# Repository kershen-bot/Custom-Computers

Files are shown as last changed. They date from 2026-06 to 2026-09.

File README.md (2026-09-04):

 # Custom-Computer

 This is a fully custom laptop that is built around a LattePanda Mu, which is a computer module that is credit card-sized. This project took around two to three and a half months. This project is inspired by Ben Makes Everything and Bryan. The specific video by Ben Makes Everything that I used is "https://www.youtube.com/watch?v=o00P7wHbd2c," and the video by Bryan that I used is "https://www.youtube.com/watch?v=fks3PBodyiE." Bryan's website is "https://www.byran.ee/" 

 Below is an image of the full shell of the custom laptop without the hinge mechanism and the internal components.

------------------------------------------------------------------------------------------------------------------------------------------


Configuration of the Lattepanda Mu,
------------------------------------------------------------------------------------------------------------------------------------------
  The exact size of the Lattepanda Mu is 69.6MM by 60MM, and the standard credit card is 85.6MM by 54MM it is very. The Lattepanda Mu has an  Intel X86 chip. It can be configured with an   N100  or an  N305 chip.  The ram that on the Lattepanda Mu is 16GB of LPDDR5 4800MT/s, and for storage, it can be equipped with an M.2 2230 NVME SSD or slash and a 64GB eMMC 5.1 Storage. And of course it has a wifi card, so you can have wifi. 

Configuration of the LattePanda Mu,
The configuration of the full device is shown below as an image.
------------------------------------------------------------------------------------------------------------------------------------------
Block Diagram

The Keyboard,
------------------------------------------------------------------------------------------------------------------------------------------
  The keyboard is a split Ortholinear keyboard because Ortholinear keyboards are easier and more natural to use. The keyboard is a fork of  Ben Makes Everything's first keyboard from his video "Building a LattePanda Mu Cyberdeck." The link to his video is https://www.youtube.com/watch?v=o00P7wHbd2c, and the time that the Ortholinear keyboard is mentioned is between the times 5:10 and 8:45. I learned how to make a  keyboard from "https://www.youtube.com/@joe_scotto"

The Trackpad on the computer,
------------------------------------------------------------------------------------------------------------------------------------------
 The trackpad is made by the company Azoteq, and the exact trackpad that I use is the PXM0091. Azoteq says itself "The IQS9150 is a generic and configurable trackpad device aimed to be suitable for numerous design variations and requirements. The PXM0091 utilizes the IQS9150 to provide high-performance multitouch (linearity, accuracy, low-noise) trackpad outputs, switch input, and an on-chip gesture recognition engine. The website that I got it from was "https://seltech-intl.com/datasheets/pxm0091.pdf." 

The ports on the Laptop,
------------------------------------------------------------------------------------------------------------------------------------------
  The laptop has four USB ports in the style of a Raspberry Pi. The HDMI port is on the back, like some gaming laptops, such as the HP OMEN MAX 16. There are a few internal USB ports, but not use the traditional ribbon connectors and cables; instead, it is using a JST connector, and there is an internal amp on the mainboard, but the BIOS and  LattePanda Mu software do not support I2S.  LattePanda said, "They will support I2S in the near future." So I decided to use a USB to audio using a rapberry pi pico to I2S, then I2S to a  USB audio converter, then to the speaker. 

The Power System
------------------------------------------------------------------------------------------------------------------------------------------
  The power button is on the main board, and it is internal, but the reason why is that when testing it, you don't need to go to the side of the laptop. But how to turn on the computer, you may ask. There is a keyboard switch on the side of the computer that is wired to the internal power button. All so there is a switch that connects directly to the battery and skips the main board and all of the software, so in an emergency, you canan switch it, and all power is shut off immediately  The battery is a 18650 4S5P battery pacl connected to an trusted AliExpress BMS, which is the  "140W 2S 3S 4S 5S 6S Lithium Battery Charging Board Bidirectional Fast Charging Li-ion Lifepo4 BMS Charger Type-C IP2366 PD3.1". Which is then connected to a 100A ANL fuse. Then it goes to a screw terminal and connects to the main board with another screw terminal, which takes the 9-12 volts from the battery. 

Battery Life of the laptop
------------------------------------------------------------------------------------------------------------------------------------------
  Battery life is a key thing when using a laptop. When you have a small battery, you have a little time on the battery, and when you have a big battery, your batter last a long time.
Number for Battery Life of the laptop
1. The battery life is about 7 hours in high-performance mode.
2. 10 hours on balanced mode.
3. On battery saver mode. It lasts about 15 hours.
  These numbers are done by math but not tested in the real world. The amount of watt-hours in the battery is 120-176 watt-hours. The legal limit for laptops that can go on planes is 99.99 watt-hours, and for battery banks it is 120-176. So if you decide to make this laptop, you can't bring it on a plane, so you have to send it to the location.

Sources & bibliography
------------------------------------------------------------------------------------------------------------------------------------------
Here are some sources I used during this project.
Keybourd
1. https://lowprokb.ca/products/kailh-choc-low-profile-switches
2. https://www.youtube.com/watch?v=bBon6WwkdJE
3. https://www.youtube.com/watch?v=8WXpGTIbxlQ
4. https://www.youtube.com/@joe_scotto
5. https://github.com/qmk/qmk_firmware
6. https://qmk.fm/
Trackpad
1. https://www.mouser.com/datasheet/2/42/Azoteq_PXM0057_20220503-2943524.pdf
2. https://www.azoteq.com/product/pxm0091/
3. https://www.mouser.ca/ProductDetail/Azoteq/IQS9150EV02-S?qs=wT7LY0lnAe1UXNco1GldIA%3D%3D
4. https://www.mouser.ca/datasheet/3/931/1/iqs9150ev02_user_guide.pdf
Battery
1. https://www.lipolbattery.com/lithium%20polymer%20battery.html
2. https://www.amazon.ca/s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

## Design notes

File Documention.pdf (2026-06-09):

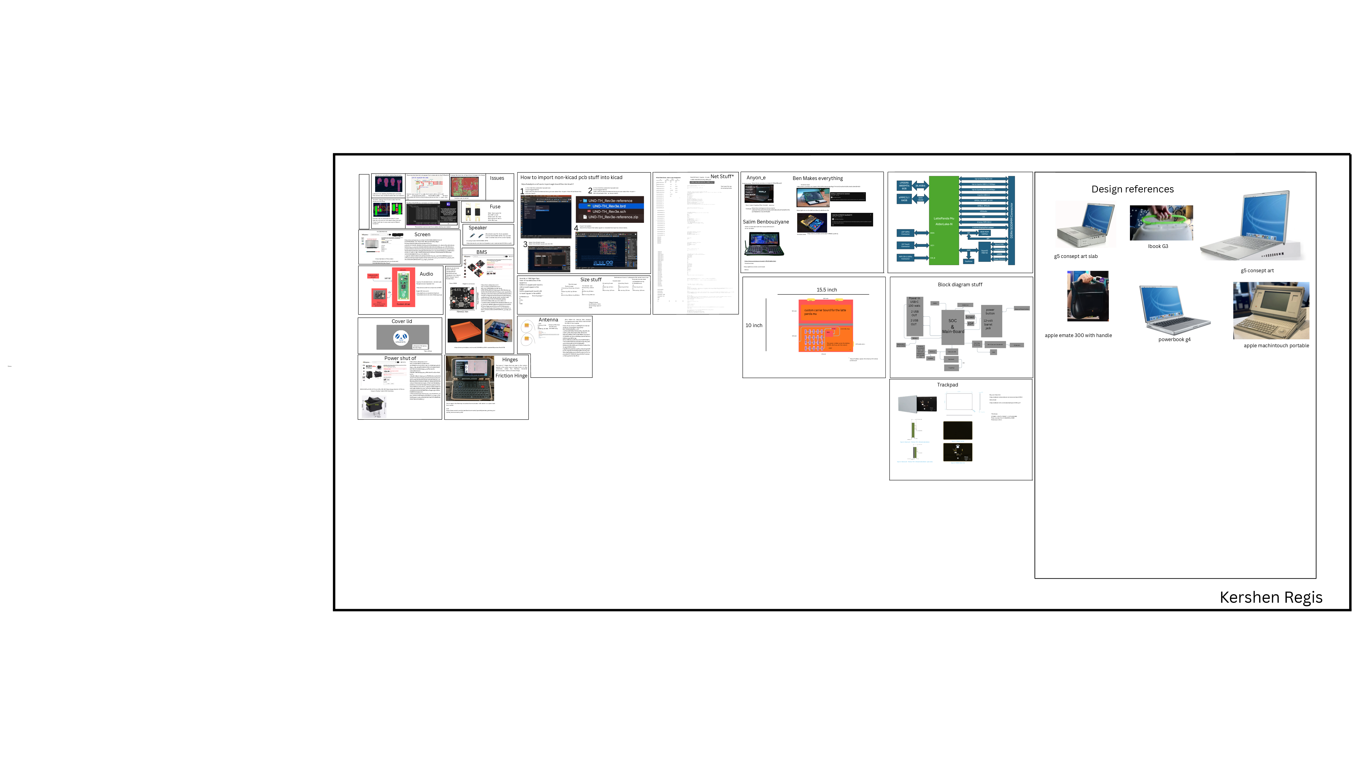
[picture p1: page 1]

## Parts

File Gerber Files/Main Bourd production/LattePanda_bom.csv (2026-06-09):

Designator | Footprint | Quantity | Value | LCSC Part #
BT1 | Battery_Holder_CR1220_S8411-45R | 1 | Battery_Cell | C964723
C17, C18, C19, C20, C21, C22, C23, C24, C25, C26, C27, C28, C29, C52, C54, C58, C60, C70, C71, C78, C79, C84 | 0402 | 22 | 100nF/50V
C30, C31, C32, C64, C65, C67, C68, C74, C75, C76, C77, C80, C81, C82, C83, C86, C89 | 0603 | 17 | 22uF/10V
C49, C50, C55, C56 | 0402 | 4 | 220nF/50V
C51, C53, C57, C59 | 0402 | 4 | 10uF/10V
C66 | 0402 | 1 | 1uF/16V
C87 | 0402 | 1 | 10uF
C88 | 0402 | 1 | 100nF
D1, D2, D21, D3, D5, D6, D7, D8 | 0402 | 8 | ESD5V0B03 | C521894
D15, D16, D17 | D_SMA | 3 | SS54 | C5200096
D22, D9 | 0603 | 2 | LED_G
D24 | D_SOD-323 | 1 | 3V3 Izt=5mA | SOD-323
D26, D4 | D_SOD-323 | 2 | 1N5819WS | C191023
DC78 | DC-IN-TH_DC-042C-W-2.0 | 1 | DC-042C-W-2.0 | C381108
F1 | 0603 | 1 | 6V/50mA | C7472508
F2, F3, F78, F79 | 0805 | 4 | 6V/1A | C883108
F4 | 0805 | 1 | 6V/2A | C883112
F5 | 0805 | 1 | 6V/2A | C883108
H5, H6 | MountingHole_3mm_M2_Pad_TopOnly | 2 | MountingHole_Pad | C5301799
H7, H8 | MountingHole_3mm_M2_Pad_TopOnly | 2 | MountingHole_M2.0 | C5301801
J15 | PCIe_M.2_Connectors_P=0.5mm_H=4.2mm_KeyM | 1 | Bus_M.2_Socket_M | C7498140
J16 | PCIe_M.2_Connectors_P=0.5mm_H=4.2mm_KeyE | 1 | Bus_M.2_Socket_E | C7498141
J3 | HDMI_A_Molex_208658-1001_Horizontal | 1 | HDMI_A | C2906135
J4 | USB3_A_Molex_48406-0001_Horizontal_Stacked | 1 | USB3_A_Stacked | C2895028
J5 | USB_A_CUI_UJ2-ADH-TH_Horizontal_Stacked | 1 | USB_A_Stacked | C7527675
J78 | TerminalBlock_bornier-2_P5.08mm | 1 | Screw_Terminal_01x02 | C394556
J79, J80 | JST_XH_B4B-XH-A_1x04_P2.50mm_Vertical | 2 | Conn_01x04_Socket | C144395
L1, L2 | L_Sunlord_SWPA4020S | 2 | 2.2uH/4.3A | C3222957
LS78 | JST_XH_B2B-XH-A_1x02_P2.50mm_Vertical | 1 | Speaker | C495685
M1 | JST_PH_B4B-PH-K_1x04_P2.00mm_Vertical | 1 | Fan_4pin | C131334
Q1, Q8 | SOT-23 | 2 | 2N7002 | C727148
Q2, Q3, Q4 | SOT-23 | 3 | 2SK3018 | C727148
R1, R11, R47 | 0402 | 3 | 1K/1%
R10, R13, R14, R16, R17, R7, R8, R9 | 0402 | 8 | 470R/1%
R15, R18, R19, R3, R30, R5, R52, R53 | 0402 | 8 | 2.2K/1%
R2, R34, R35, R49, R58, R78, R79 | 0402 | 7 | 10K/1%
R27, R29, R32, R33 | 0402 | 4 | 0R/1%
R4 | 0402 | 1 | 1M/1%
R46, R48, R69 | 0402 | 3 | 100R/1%
R51, R76, R77 | 0402 | 3 | 100K/1%
R57 | 0402 | 1 | 75K/1%
R59, R6, R68 | 0402 | 3 | 21.5K/1%
R60, R72 | 0402 | 2 | 4.7K/1%
R80 | 0402 | 1 | 1M
SW1 | SW-TH_TM-007-D1-A-03 | 1 | SW_Push | C5184999
TP2, TP4 | TestPoint_Pad_D1.5mm | 2 | TestPoint
U1, U2 | Diodes_UDFN-10_1.0x2.5mm_P0.5mm | 2 | TPAZ1023-04F | C1980462
U15, U16 | TSOT-23-6 | 2 | SY8253ADC | C93736
U3, U4, U5, U78 | Diodes_UDFN-10_1.0x2.5mm_P0.5mm | 4 | ULC0524P | C1980462
U79 | 21-0136I_T1633-4_MXM | 1 | MAX98357AETE+T | C910544

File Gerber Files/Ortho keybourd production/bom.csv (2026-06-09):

Designator | Footprint | Quantity | Value | LCSC Part #
D1, D10, D11, D12, D13, D14, D15, D16, D17, D18, D19, D2, D20, D21, D22, D23, D24, D25, D26, D27, D28, D29, D3, D30, D31, D32, D33, D34, D35, D36, D37, D38, D39, D4, D40, D41, D42, D43, D44, D45, D46, D47, D48, D49, D5, D50, D51, D52, D53, D54, D55, D56, D57, D58, D59, D6, D60, D61, D62, D7, D8, D9 | Diode_SOD-123 | 62 | Diode | 1N4148W-7-F

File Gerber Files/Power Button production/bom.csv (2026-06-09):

Designator | Footprint | Quantity | Value | LCSC Part #
S1 | MX_Solder_1.00u | 1 | ~

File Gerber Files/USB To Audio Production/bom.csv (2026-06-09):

Designator | Footprint | Quantity | Value | LCSC Part #
U1 | Raspberry_Pi_Pico | 1 | Raspberry_Pi_Pico

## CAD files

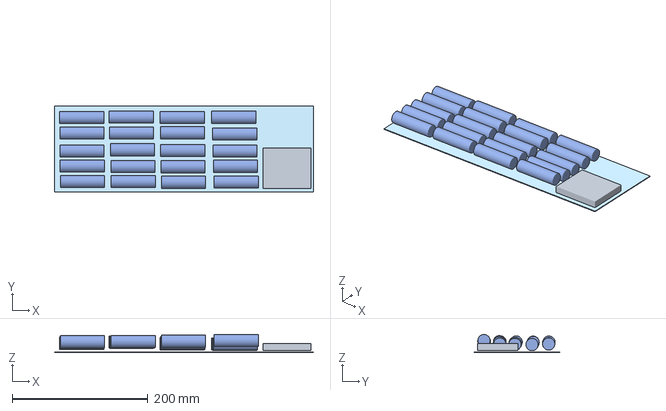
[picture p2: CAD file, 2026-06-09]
3D Moduls/Full battery Assembly.step
381.0 x 127.0 x 26.6 mm
id15

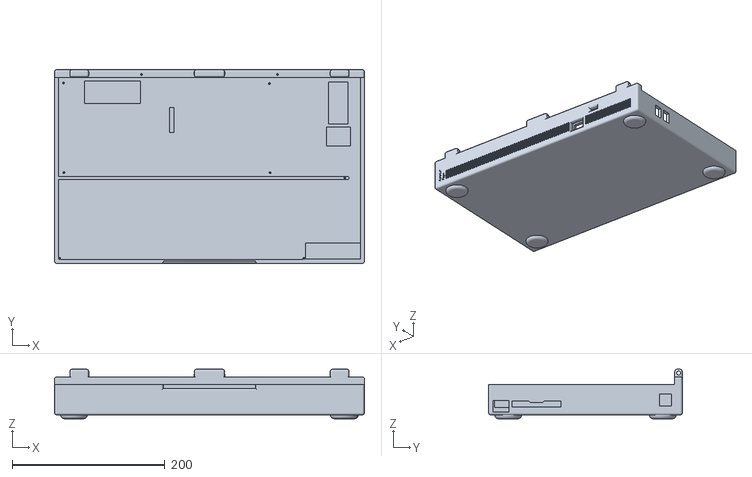
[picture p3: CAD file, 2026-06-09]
3D Moduls/Main Body - Main Body.stl
406.4 x 254.0 x 65.0

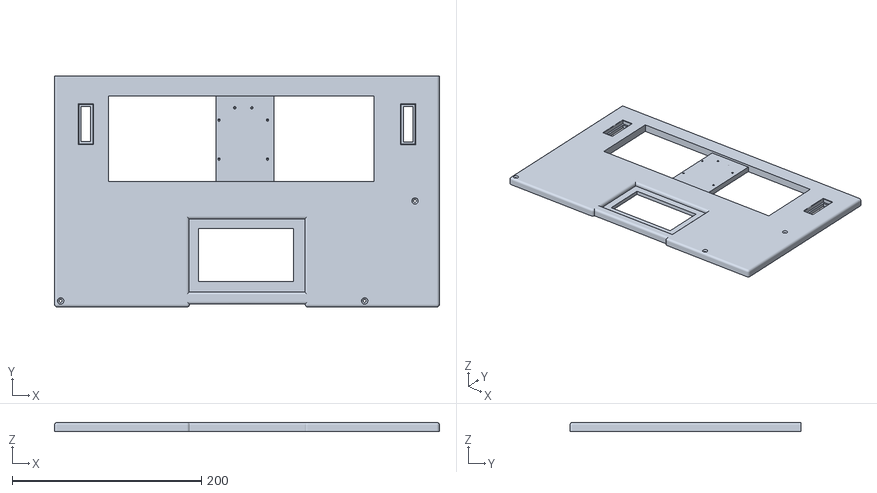
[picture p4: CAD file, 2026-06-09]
3D Moduls/Keybourd Cover - Keybourd Cover.stl
406.4 x 244.0 x 10.0

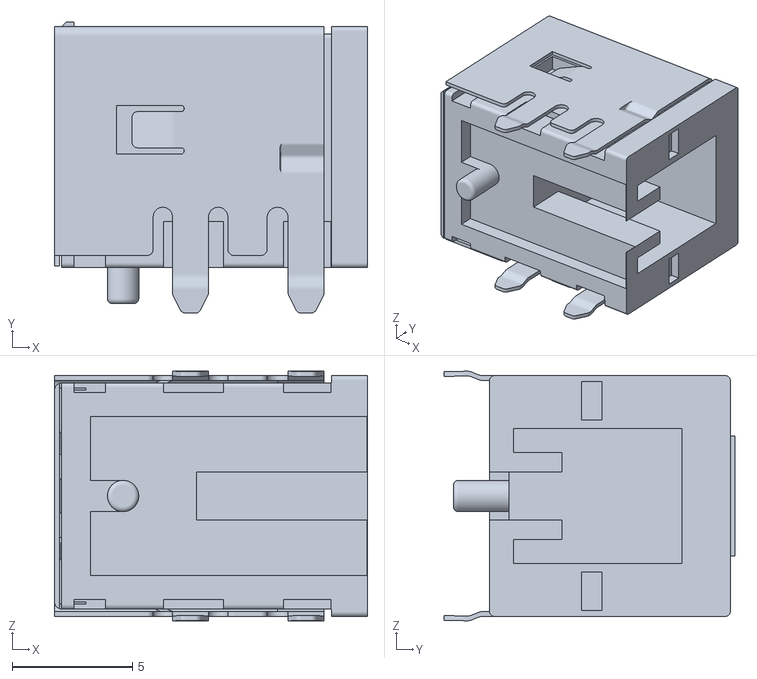
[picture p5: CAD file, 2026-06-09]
Main Bourd/3D_models/DC jack/DC-IN-TH_DC-042C-W-2.stl
13.0 x 12.1 x 10.4

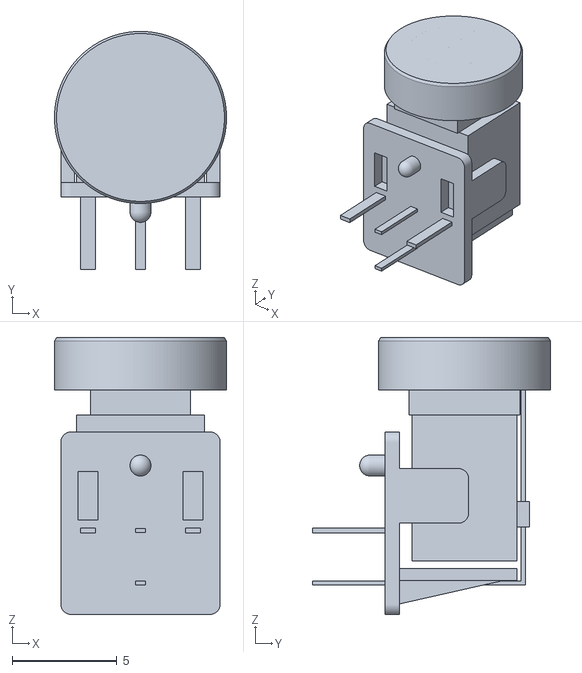
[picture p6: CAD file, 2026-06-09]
Main Bourd/3D_models/Switch/SW-TH_TM-007-D1-A-03.stl
8.20 x 11.3 x 13.2

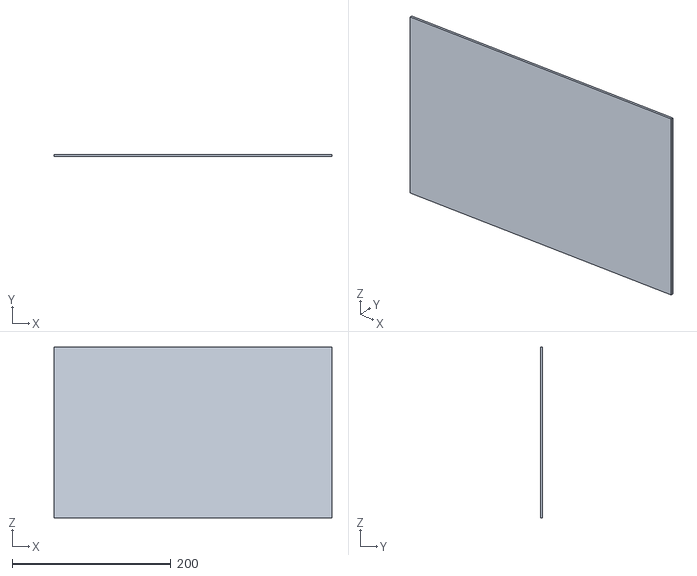
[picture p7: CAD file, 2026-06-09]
3D Moduls/Screen.stl
350.7 x 2.60 x 215.2

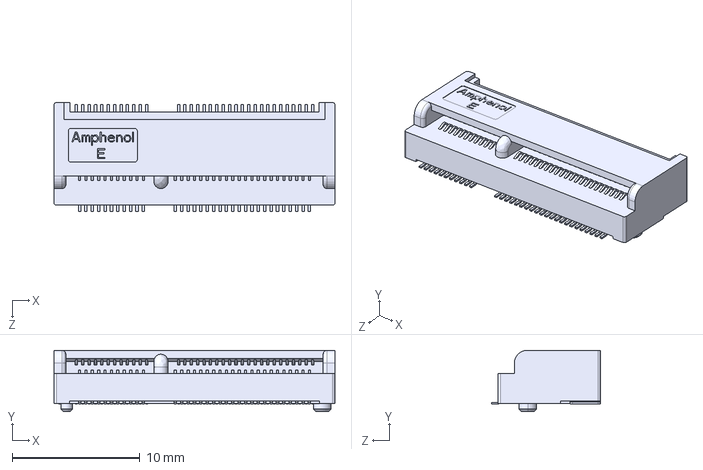
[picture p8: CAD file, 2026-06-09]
Main Bourd/3D_models/MDT420E02001.step
22.0 x 4.80 x 8.55 mm

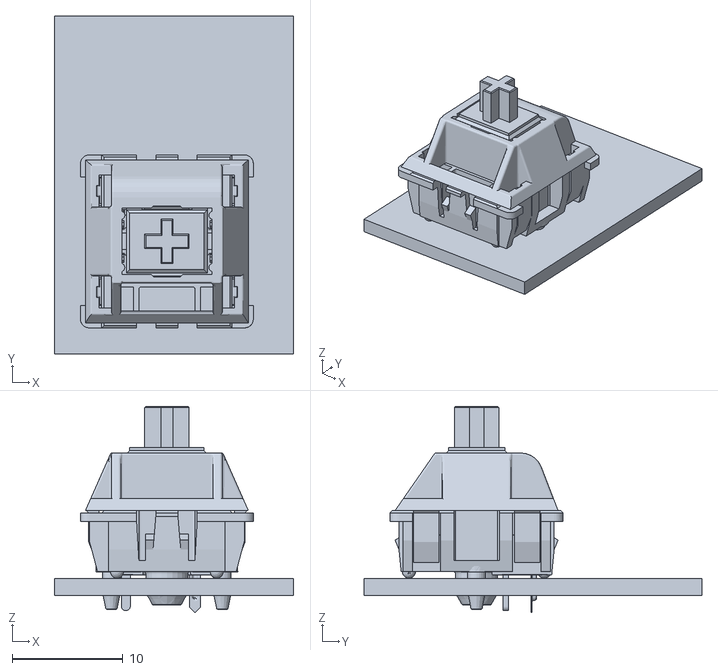
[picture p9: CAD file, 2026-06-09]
3D Moduls/Power Button.stl
21.6 x 30.5 x 18.6

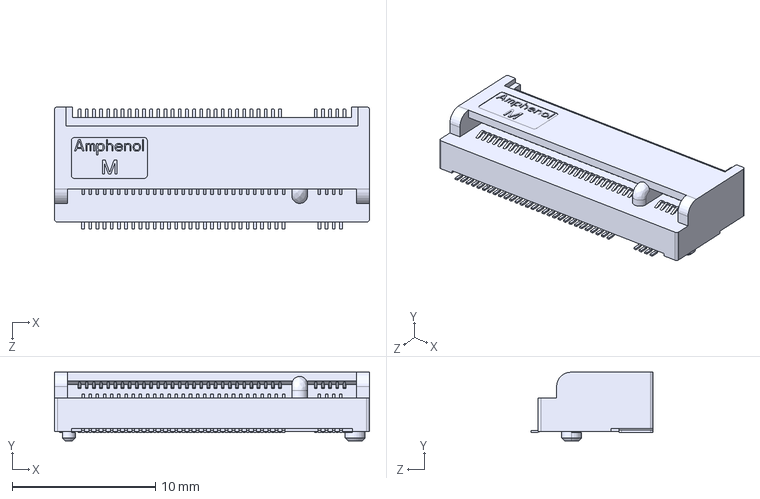
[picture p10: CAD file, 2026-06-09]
Main Bourd/3D_models/MDT420M02001.step
22.0 x 4.80 x 8.55 mm

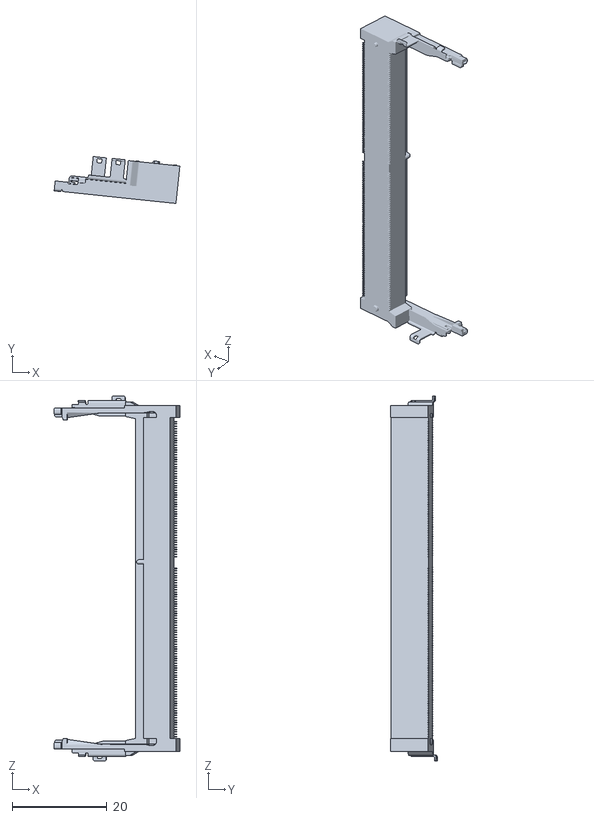
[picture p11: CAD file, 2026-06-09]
3D Moduls/DDR4 SO-DIM connecter.stl
26.5 x 9.91 x 77.0

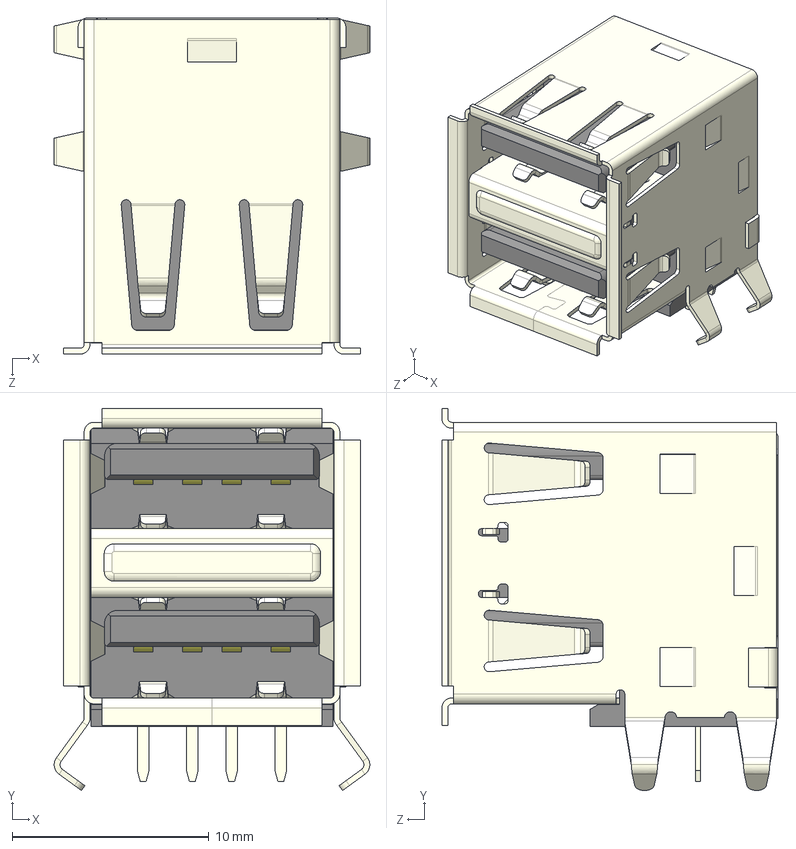
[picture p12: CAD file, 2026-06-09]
Main Bourd/3D_models/Same_Sky_UJ2-ADH-3-TH.step
16.0 x 19.4 x 17.1 mm

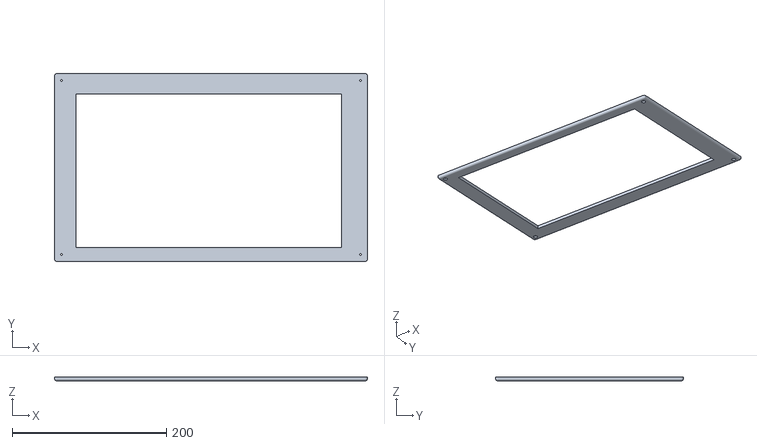
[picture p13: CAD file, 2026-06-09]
3D Moduls/Screen Bezel - Screen Bezel.stl
406.4 x 244.0 x 5.00

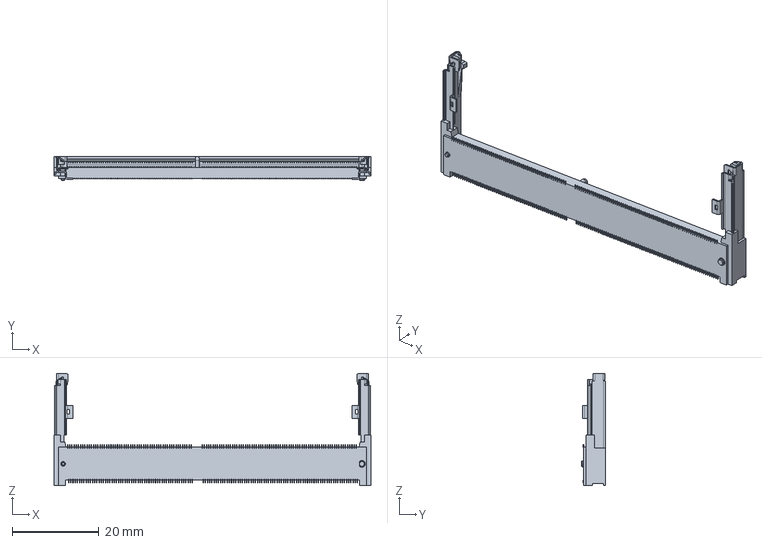
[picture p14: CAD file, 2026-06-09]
Main Bourd/3D_models/SO-DIMM.stp
73.0 x 5.55 x 25.9 mm

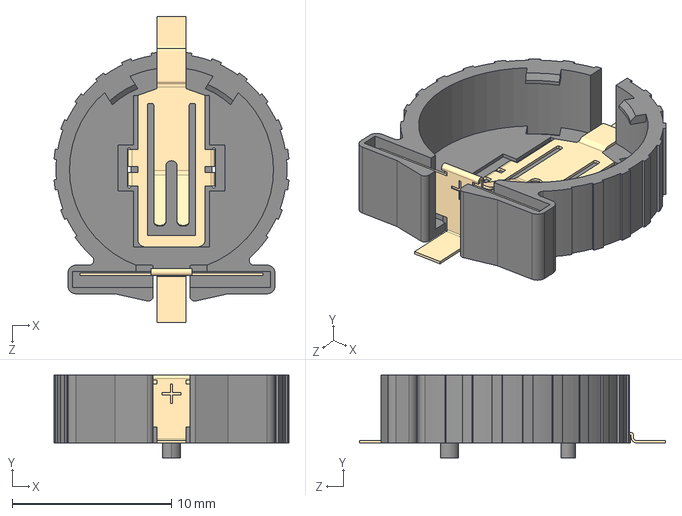
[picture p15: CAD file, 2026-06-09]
Main Bourd/3D_models/S8411-45R.step
14.7 x 5.20 x 19.2 mm

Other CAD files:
3D Moduls/Speaker.stl
3D Moduls/Speaker AS04004MO-SP40.stl
3D Moduls/Hinge Pin - Hinge Pin.stl
3D Moduls/LattePanda_Mu.step
3D Moduls/18650 Cell.stl
3D Moduls/Adafruit TLV320DAC3100 I2S DAC.stl
3D Moduls/Hinge Pin End - Hinge Pin End.stl
3D Moduls/Top Cover - Top Cover.stl
3D Moduls/Trackpad.stl
Main Bourd/3D_models/2086581001.step
Main Bourd/3D_models/2086581001.stp
Main Bourd/3D_models/48406-0001.stp

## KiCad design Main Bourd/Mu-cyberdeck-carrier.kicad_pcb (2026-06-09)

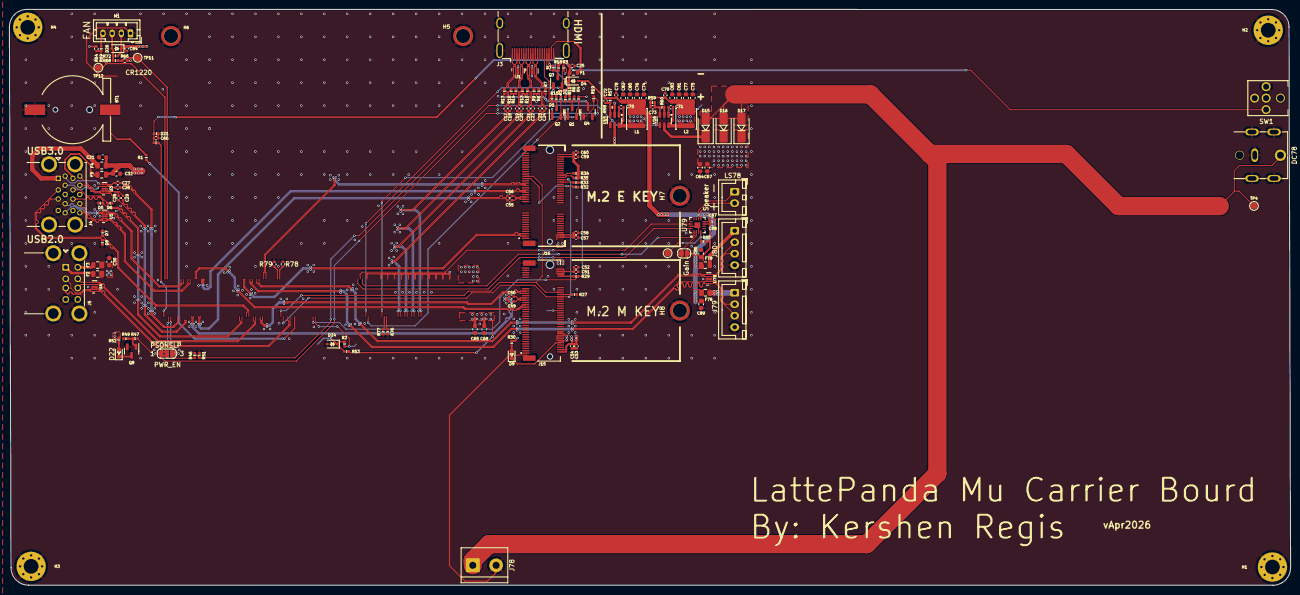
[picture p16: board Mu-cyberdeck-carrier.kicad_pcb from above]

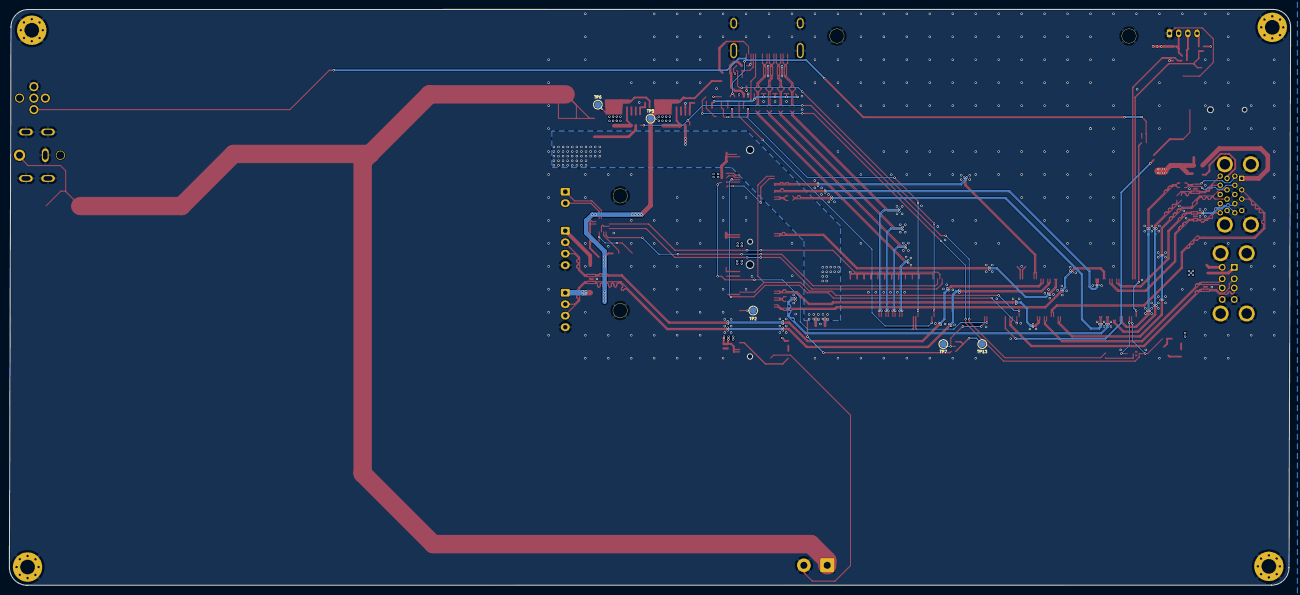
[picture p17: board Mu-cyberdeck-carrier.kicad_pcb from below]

Board: 4 copper layers, 279.0 x 125.4 mm, 169 parts (5 on the bottom side), 90 nets.

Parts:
BT1: Battery_Cell; Battery_Holder_CR1220_S8411-45R
C17, C18, C19, C20, C21, C22, C23, C24, C25, C26, C27, C28, C29, C52, C54, C58, C60, C70, C71, C78, C79, C84: 100nF/50V; C_0402_1005Metric
C30, C31, C32, C64, C65, C67, C68, C74, C75, C76, C77, C80, C81, C82, C83, C86, C89: 22uF/10V; C_0603_1608Metric
C49, C50, C55, C56: 220nF/50V; C_0402_1005Metric
C51, C53, C57, C59: 10uF/10V; C_0402_1005Metric
C66: 1uF/16V; C_0402_1005Metric
C72, C73: 12pF/50V; C_0402_1005Metric
C87: 10uF; C_0402_1005Metric
C88: 100nF; C_0402_1005Metric
D1, D2, D3, D5, D6, D7, D8, D21: ESD5V0B03; D_0402_1005Metric
D4, D26: 1N5819WS; D_SOD-323
D9, D22: LED_G; LED_0603_1608Metric
D15, D16, D17: SS54; D_SMA
D24: 3V3 Izt=5mA; D_SOD-323
DC78: DC-042C-W-2.0; DC-IN-TH_DC-042C-W-2.0
F1: 6V/50mA; R_0603_1608Metric
F2, F3, F78, F79: 6V/1A; Fuse_0805_2012Metric
F4: 6V/2A; R_0805_2012Metric
F5: 6V/2A; Fuse_0805_2012Metric
Gain: SolderJumper_2_Open; SolderJumper-2_P1.3mm_Open_RoundedPad1.0x1.5mm
H1, H2, H3, H4: MountingHole_Pad; MountingHole_3.2mm_M3_Pad_Via
H5, H6: MountingHole_Pad; MountingHole_3mm_M2_Pad_TopOnly
H7, H8: MountingHole_M2.0; MountingHole_3mm_M2_Pad_TopOnly
J3: HDMI_A; HDMI_A_Molex_208658-1001_Horizontal
J4: USB3_A_Stacked; USB3_A_Molex_48406-0001_Horizontal_Stacked
J5: USB_A_Stacked; USB_A_CUI_UJ2-ADH-TH_Horizontal_Stacked
J15: Bus_M.2_Socket_M; PCIe_M.2_Connectors_P=0.5mm_H=4.2mm_KeyM
J16: Bus_M.2_Socket_E; PCIe_M.2_Connectors_P=0.5mm_H=4.2mm_KeyE
J78: Screw_Terminal_01x02; TerminalBlock_bornier-2_P5.08mm
J79, J80: Conn_01x04_Socket; JST_XH_B4B-XH-A_1x04_P2.50mm_Vertical
JP79: SolderJumper_3_Open; SolderJumper-3_P1.3mm_Bridged2Bar12_RoundedPad1.0x1.5mm_Num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
L1, L2: 2.2uH/4.3A; L_Sunlord_SWPA4020S
LS78: Speaker; JST_XH_B2B-XH-A_1x02_P2.50mm_Vertical
M1: Fan_4pin; JST_PH_B4B-PH-K_1x04_P2.00mm_Vertical
Q1, Q8: 2N7002; SOT-23
Q2, Q3, Q4: 2SK3018; SOT-23
R1, R11, R47: 1K/1%; R_0402_1005Metric
R2, R34, R35, R49, R58, R78, R79: 10K/1%; R_0402_1005Metric
R3, R5, R15, R18, R19, R30, R52, R53: 2.2K/1%; R_0402_1005Metric
R4: 1M/1%; R_0402_1005Metric
R6, R59, R66, R68: 21.5K/1%; R_0402_1005Metric
R7, R8, R9, R10, R13, R14, R16, R17: 470R/1%; R_0402_1005Metric
R27, R29, R32, R33: 0R/1%; R_0402_1005Metric
R46, R48, R69: 100R/1%; R_0402_1005Metric
R51, R76, R77: 100K/1%; R_0402_1005Metric
R57: 75K/1%; R_0402_1005Metric
R60, R64, R72: 4.7K/1%; R_0402_1005Metric
R80: 1M; R_0402_1005Metric
SD_Mode: TestPoint; TestPoint_Pad_D1.5mm
SW1: SW_Push; SW-TH_TM-007-D1-A-03
TP2, TP4, TP5, TP6, TP7, TP11, TP12, TP13: TestPoint; TestPoint_Pad_D1.5mm
U1, U2: TPAZ1023-04F; Diodes_UDFN-10_1.0x2.5mm_P0.5mm
U3, U4, U5, U78: ULC0524P; Diodes_UDFN-10_1.0x2.5mm_P0.5mm
U15, U16: SY8253ADC; TSOT-23-6
U79: MAX98357AETE+T; 21-0136I_T1633-4_MXM

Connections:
5V_HDMI_VCC: C25.1, D4.1 (K), F1.1, R15.1, R18.1
+3V3: C51.2, C52.2, C53.2, C54.2, C57.2, C58.2, C59.2, C60.2, C73.1, C75.2, C77.2, C79.1, C81.2, C83.2, J15.2 (3.3V), J15.4 (3.3V), J15.12 (3.3V), J15.14 (3.3V), J15.16 (3.3V), J15.18 (3.3V), J15.70 (3.3V), J15.72 (3.3V), J15.74 (3.3V), J16.2 (3.3V), J16.4 (3.3V), J16.72 (3.3V), J16.74 (3.3V), L2.2, Q1.1 (G), Q2.1 (G), Q3.1 (G), R3.1, R4.1, R5.1, R30.2, R34.2, R35.1, R52.2, R59.2, R64.1, TP6.1
+5V: C30.2, C31.2, C32.2, C72.1, C74.2, C76.2, C78.1, C80.2, C82.2, C84.1, C86.2, C87.1, C88.1, C89.2, D4.2 (A), D26.1 (K), F2.1, F3.1, F4.1, F5.1, F78.1, F79.1, Gain.1 (A), L1.2, M1.2 (+), R57.2, R72.1, R80.1, TP5.1, U79.7 (VDD), U79.8 (VDD)
+12V: D15.2 (A), D16.2 (A), D17.2 (A), DC78.4, J78.1, TP4.1
/Fan_Temp/FAN_1_PWM: R64.2, R69.1, TP12.1
/Fan_Temp/FAN_1_TAC: R66.1, R68.2, TP11.1
/HDMI/DDC_SCL: D1.2 (A2), J3.15 (SCL), Q2.3 (D), R15.2
/HDMI/DDC_SDA: D3.2 (A2), J3.16 (SDA), Q3.3 (D), R18.2
/HDMI/DDI_B_DDC_SCL: Q2.2 (S), R5.2
/HDMI/DDI_B_DDC_SDA: Q3.2 (S), R3.2
/HDMI/DDI_B_HPD: Q1.2 (S), R4.2
/HDMI/HPD: D2.2 (A2), J3.19 (HPD), R11.2
/HDMI/TMDS_CK+: C23.2, J3.10 (CK+), R8.1, U2.4, U2.7 (NC)
/HDMI/TMDS_CK-: C24.2, J3.12 (CK-), R7.1, U2.5, U2.6 (NC)
/HDMI/TMDS_D0+: C21.2, J3.7 (D0+), R10.1, U2.1, U2.10 (NC)
/HDMI/TMDS_D0-: C22.2, J3.9 (D0-), R9.1, U2.2, U2.9 (NC)
/HDMI/TMDS_D1+: C19.2, J3.4 (D1+), R14.1, U1.4, U1.7 (NC)
/HDMI/TMDS_D1-: C20.2, J3.6 (D1-), R13.1, U1.5, U1.6 (NC)
/HDMI/TMDS_D2+: C17.2, J3.1 (D2+), R17.1, U1.1, U1.10 (NC)
/HDMI/TMDS_D2-: C18.2, J3.3 (D2-), R16.1, U1.2, U1.9 (NC)
/LattePanda Module/SUSCLK_WIFI: R29.2, R33.2
/M.2 E&M Key/CON_PCIE_TX_0+: C55.2, J16.35 (PETp0)
/M.2 E&M Key/CON_PCIE_TX_0-: C56.2, J16.37 (PETn0)
/M.2 E&M Key/CON_PCIE_TX_1+: C49.2, J15.49 (PETp0/SATA-A+)
/M.2 E&M Key/CON_PCIE_TX_1-: C50.2, J15.47 (PETn0/SATA-A-)
/M.2 E&M Key/~CLKREQE: J16.53 (~CLKREQ0), R32.1
/M.2 E&M Key/~CLKREQM: J15.52 (~CLKREQ), R27.1
/PSU/PWR_EN: R46.2, R51.2, U15.4 (EN), U16.4 (EN)
/USB2.0&USB3.0/CON_USB1_D_N: J5.2 (D1-), U4.2, U4.9 (NC)
/USB2.0&USB3.0/CON_USB1_D_P: J5.3 (D1+), U4.1, U4.10 (NC)
/USB2.0&USB3.0/CON_USB2_D_N: J5.6 (D2-), U4.5, U4.6 (NC)
/USB2.0&USB3.0/CON_USB2_D_P: J5.7 (D2+), U4.4, U4.7 (NC)
/USB2.0&USB3.0/CON_USB3_D_N: D8.2 (A2), J4.2 (D1-)
/USB2.0&USB3.0/CON_USB3_D_P: D7.2 (A2), J4.3 (D1+)
/USB2.0&USB3.0/CON_USB3_SSRX_N: J4.5 (SSRX1-), U5.4, U5.7 (NC)
/USB2.0&USB3.0/CON_USB3_SSRX_P: J4.6 (SSRX1+), U5.5, U5.6 (NC)
/USB2.0&USB3.0/CON_USB3_SSTX_N: C26.2, J4.8 (SSTX1-), U3.4, U3.7 (NC)
/USB2.0&USB3.0/CON_USB3_SSTX_P: C27.2, J4.9 (SSTX1+), U3.5, U3.6 (NC)
/USB2.0&USB3.0/CON_USB4_D_N: D6.2 (A2), J4.11 (D2-)
/USB2.0&USB3.0/CON_USB4_D_P: D5.2 (A2), J4.12 (D2+)
/USB2.0&USB3.0/CON_USB4_SSRX_N: J4.14 (SSRX2-), U5.1, U5.10 (NC)
/USB2.0&USB3.0/CON_USB4_SSRX_P: J4.15 (SSRX2+), U5.2, U5.9 (NC)
/USB2.0&USB3.0/CON_USB4_SSTX_N: C28.2, J4.17 (SSTX2-), U3.1, U3.10 (NC)
/USB2.0&USB3.0/CON_USB4_SSTX_P: C29.2, J4.18 (SSTX2+), U3.2, U3.9 (NC)
/~PLT_RST: J15.50 (~PERST), J16.52 (~PERST0)
/~PWR_LED/~PSON: JP79.1 (A), R19.1, R47.1
/~WAKE: J15.54 (~PEWAKE), J16.55 (~PEWAKE0)
GND: BT1.2 (-), C25.2, C30.1, C31.1, C32.1, C51.1, C52.1, C53.1, C54.1, C57.1, C58.1, C59.1, C60.1, C64.1, C65.1, C66.2, C67.1, C68.1, C74.1, C75.1, C76.1, C77.1, C78.2, C79.2, C80.1, C81.1, C82.1, C83.1, C84.2, C86.1, C87.2, C88.2, C89.1, D1.1 (A1), D2.1 (A1), D3.1 (A1), D5.1 (A1), D6.1 (A1), D7.1 (A1), D8.1 (A1), D21.1 (A1), D24.2 (A), DC78.2, DC78.3, H1.1, H2.1, H3.1, H4.1, H5.1, H6.1, H7.1, H8.1, J3.2 (D2S), J3.5 (D1S), J3.8 (D0S), J3.11 (CKS), J3.17 (GND), J3.SH, J4.4 (GND1), J4.7 (DRAIN1), J4.13 (GND2), J4.16 (DRAIN2), J4.19 (SHIELD), J5.4 (GND1), J5.8 (GND2), J5.9 (Shield), J15.1 (GND), J15.3 (GND), J15.9 (GND), J15.15 (GND), J15.21 (GND), J15.27 (GND), J15.33 (GND), J15.39 (GND), J15.45 (GND), J15.51 (GND), J15.57 (GND), J15.71 (GND), J15.73 (GND), J15.75 (GND), J15.MP1, J15.MP2, J16.1 (GND), J16.7 (GND), J16.18 (GND), J16.33 (GND), J16.39 (GND), J16.45 (GND), J16.51 (GND), J16.57 (GND), J16.63 (GND), J16.69 (GND), J16.75 (GND), J16.MP1, J16.MP2, J78.2, J79.4, J80.4, M1.1 (-), Q4.2 (S), Q8.2 (S), R6.2, R27.2, R32.2, R49.1, R51.1, R58.1, R60.1, R66.2, R76.2, R77.2, R78.2, R79.2, SW1.2, U1.3 (VSS), U1.8 (VSS), U2.3 (VSS), U2.8 (VSS), U3.3 (VSS), U3.8 (VSS), U4.3 (VSS), U4.8 (VSS), U5.3 (VSS), U5.8 (VSS), U15.2 (GND), U16.2 (GND), U78.3 (VSS), U78.8 (VSS), U79.3 (GND), U79.11 (GND), U79.15 (GND), U79.17 (EPAD)
unnamed: R2.1, TP7.1
unnamed: BT1.1 (+), R1.2
unnamed: D9.2 (A), R30.1
unnamed: D9.1 (K), J15.10 (DAS/~DSS/~LED1)
unnamed: D22.2 (A), R52.1
unnamed: D22.1 (K), Q8.3 (D)
unnamed: D26.2 (A), M1.3 (Tacho), R68.1, R72.2
unnamed: F1.2, J3.18 (+5V)
unnamed: F4.2, J4.1 (VBUS1)
unnamed: F5.2, J4.10 (VBUS2)
unnamed: F2.2, J5.1 (VBUS1)
unnamed: F3.2, J5.5 (VBUS2)
unnamed: J15.38 (DEVSLP), TP2.1
unnamed: J15.68 (SUSCLK), R29.1
unnamed: J16.50 (SUSCLK), R33.1
unnamed: J16.56 (~W_DISABLE1), R34.1
unnamed: J16.54 (~W_DISABLE2), R35.2
unnamed: F78.2, J79.1
unnamed: F79.2, J80.1
unnamed: Gain.2 (B), U79.2 (GAIN_SLOT)
unnamed: JP79.2 (C), R46.1
unnamed: M1.4 (PWM), R69.2
unnamed: Q1.3 (D), R6.1, R11.1
unnamed: Q4.3 (D), R7.2, R8.2, R9.2, R10.2, R13.2, R14.2, R16.2, R17.2
unnamed: Q4.1 (G), R19.2
unnamed: Q8.1 (G), R47.2, R49.2
unnamed: C70.2, U15.1 (BOOST)
unnamed: C72.2, R57.1, R58.2, U15.3 (FB)
unnamed: C70.1, L1.1, U15.6 (SW)
unnamed: C71.2, U16.1 (BOOST)
unnamed: C73.2, R59.1, R60.2, U16.3 (FB)
unnamed: C71.1, L2.1, U16.6 (SW)
unnamed: R80.2, SD_Mode.1, U79.4 (*SD_MODE)
unnamed: LS78.1, U79.10 (OUTN)
unnamed: LS78.2, U79.9 (OUTP)
PWR: C66.1, D21.2 (A2), R48.1, SW1.1
USB_2_FP1+: J79.3, U78.1, U78.10 (NC)
USB_2_FP1-: J79.2, U78.2, U78.9 (NC)
USB_2_FP2+: J80.3, U78.4, U78.7 (NC)
USB_2_FP2-: J80.2, U78.5, U78.6 (NC)
VDC: C64.2, C65.2, C67.2, C68.2, D15.1 (K), D16.1 (K), D17.1 (K), R53.1, U15.5 (VIN), U16.5 (VIN)
VPullup: D24.1 (K), R2.2, R53.2, TP13.1

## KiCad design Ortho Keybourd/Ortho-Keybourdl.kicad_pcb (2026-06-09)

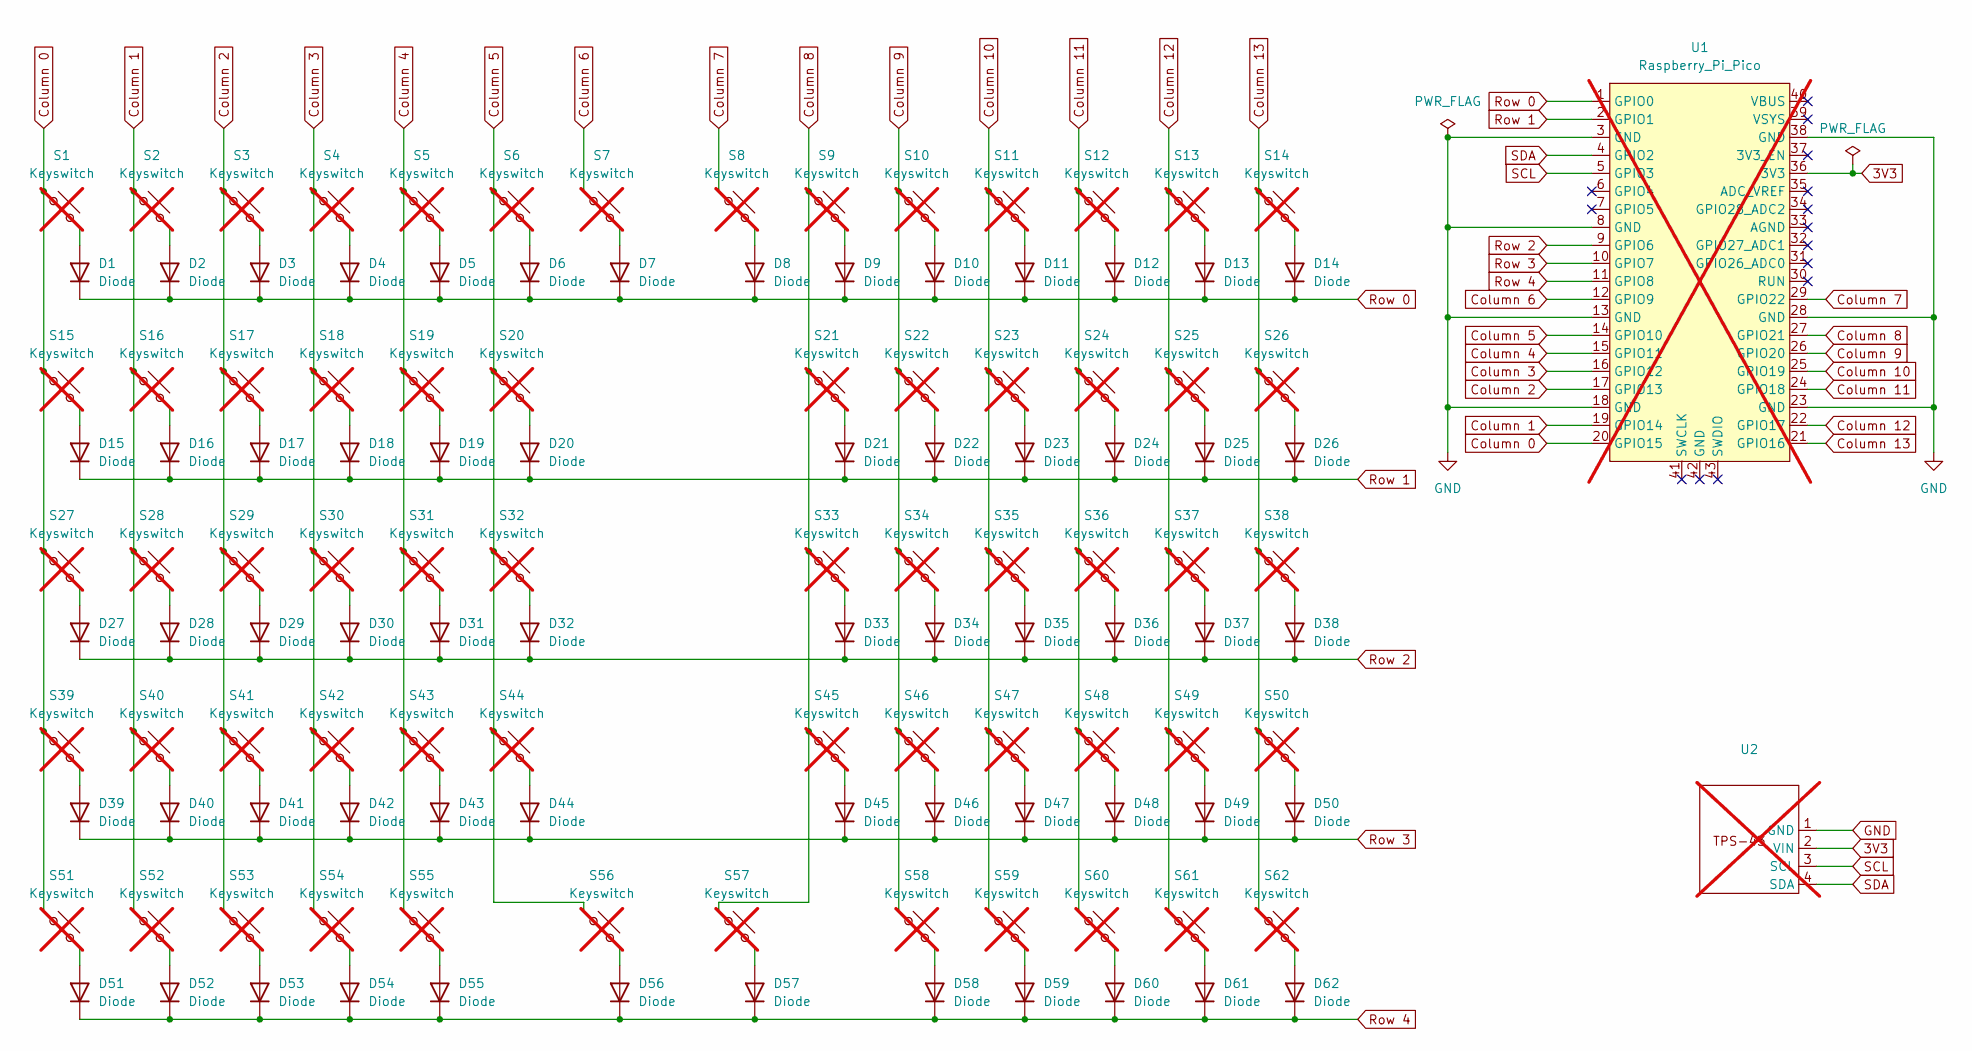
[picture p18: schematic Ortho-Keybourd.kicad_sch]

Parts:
D1, D2, D3, D4, D5, D6, D7, D8, D9, D10, D11, D12, D13, D14, D15, D16, D17, D18, D19, D20, D21, D22, D23, D24, D25, D26, D27, D28, D29, D30, D31, D32, D33, D34, D35, D36, D37, D38, D39, D40, D41, D42, D43, D44, D45, D46, D47, D48, D49, D50, D51, D52, D53, D54, D55, D56, D57, D58, D59, D60, D61, D62: Diode; Diode_SOD-123; MPN 1N4148W-7-F
S1, S2, S3, S4, S5, S6, S7, S8, S9, S10, S11, S12, S13, S14, S15, S16, S17, S18, S19, S20, S21, S22, S23, S24, S25, S26, S27, S28, S29, S30, S31, S32, S33, S34, S35, S36, S37, S38, S39, S40, S41, S42, S43, S44, S45, S46, S47, S48, S49, S50, S51, S52, S53, S54, S56, S57, S59, S60, S61, S62: Keyswitch; Choc_V1; not fitted
S55, S58: Keyswitch; Choc_V1_2.00u; not fitted
U1: Raspberry_Pi_Pico; not fitted
U2: PinHeader_1x04_P2.54mm_Vertical; not fitted

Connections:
3V3: U1.36 (3V3), U2.2 (VIN)
Column 0: S1.1, S15.1, S27.1, S39.1, S51.1, U1.20 (GPIO15)
Column 1: S2.1, S16.1, S28.1, S40.1, S52.1, U1.19 (GPIO14)
Column 2: S3.1, S17.1, S29.1, S41.1, S53.1, U1.17 (GPIO13)
Column 3: S4.1, S18.1, S30.1, S42.1, S54.1, U1.16 (GPIO12)
Column 4: S5.1, S19.1, S31.1, S43.1, S55.1, U1.15 (GPIO11)
Column 5: S6.1, S20.1, S32.1, S44.1, S56.1, U1.14 (GPIO10)
Column 6: S7.1, U1.12 (GPIO9)
Column 7: S8.1, U1.29 (GPIO22)
Column 8: S9.1, S21.1, S33.1, S45.1, S57.1, U1.27 (GPIO21)
Column 9: S10.1, S22.1, S34.1, S46.1, S58.1, U1.26 (GPIO20)
Column 10: S11.1, S23.1, S35.1, S47.1, S59.1, U1.25 (GPIO19)
Column 11: S12.1, S24.1, S36.1, S48.1, S60.1, U1.24 (GPIO18)
Column 12: S13.1, S25.1, S37.1, S49.1, S61.1, U1.22 (GPIO17)
Column 13: S14.1, S26.1, S38.1, S50.1, S62.1, U1.21 (GPIO16)
GND: U1.3 (GND), U1.8 (GND), U1.13 (GND), U1.18 (GND), U1.23 (GND), U1.28 (GND), U1.38 (GND), U2.1 (GND)
unnamed: D1.2 (A), S1.2
unnamed: D2.2 (A), S2.2
unnamed: D3.2 (A), S3.2
unnamed: D4.2 (A), S4.2
unnamed: D5.2 (A), S5.2
unnamed: D6.2 (A), S6.2
unnamed: D7.2 (A), S7.2
unnamed: D8.2 (A), S8.2
unnamed: D9.2 (A), S9.2
unnamed: D10.2 (A), S10.2
unnamed: D11.2 (A), S11.2
unnamed: D12.2 (A), S12.2
unnamed: D13.2 (A), S13.2
unnamed: D14.2 (A), S14.2
unnamed: D15.2 (A), S15.2
unnamed: D16.2 (A), S16.2
unnamed: D17.2 (A), S17.2
unnamed: D18.2 (A), S18.2
unnamed: D19.2 (A), S19.2
unnamed: D20.2 (A), S20.2
unnamed: D21.2 (A), S21.2
unnamed: D22.2 (A), S22.2
unnamed: D23.2 (A), S23.2
unnamed: D24.2 (A), S24.2
unnamed: D25.2 (A), S25.2
unnamed: D26.2 (A), S26.2
unnamed: D27.2 (A), S27.2
unnamed: D28.2 (A), S28.2
unnamed: D29.2 (A), S29.2
unnamed: D30.2 (A), S30.2
unnamed: D31.2 (A), S31.2
unnamed: D32.2 (A), S32.2
unnamed: D33.2 (A), S33.2
unnamed: D34.2 (A), S34.2
unnamed: D35.2 (A), S35.2
unnamed: D36.2 (A), S36.2
unnamed: D37.2 (A), S37.2
unnamed: D38.2 (A), S38.2
unnamed: D39.2 (A), S39.2
unnamed: D40.2 (A), S40.2
unnamed: D41.2 (A), S41.2
unnamed: D42.2 (A), S42.2
unnamed: D43.2 (A), S43.2
unnamed: D44.2 (A), S44.2
unnamed: D45.2 (A), S45.2
unnamed: D46.2 (A), S46.2
unnamed: D47.2 (A), S47.2
unnamed: D48.2 (A), S48.2
unnamed: D49.2 (A), S49.2
unnamed: D50.2 (A), S50.2
unnamed: D51.2 (A), S51.2
unnamed: D52.2 (A), S52.2
unnamed: D53.2 (A), S53.2
unnamed: D54.2 (A), S54.2
unnamed: D55.2 (A), S55.2
unnamed: D56.2 (A), S56.2
unnamed: D57.2 (A), S57.2
unnamed: D58.2 (A), S58.2
unnamed: D59.2 (A), S59.2
unnamed: D60.2 (A), S60.2
unnamed: D61.2 (A), S61.2
unnamed: D62.2 (A), S62.2
Row 0: D1.1 (K), D2.1 (K), D3.1 (K), D4.1 (K), D5.1 (K), D6.1 (K), D7.1 (K), D8.1 (K), D9.1 (K), D10.1 (K), D11.1 (K), D12.1 (K), D13.1 (K), D14.1 (K), U1.1 (GPIO0)
Row 1: D15.1 (K), D16.1 (K), D17.1 (K), D18.1 (K), D19.1 (K), D20.1 (K), D21.1 (K), D22.1 (K), D23.1 (K), D24.1 (K), D25.1 (K), D26.1 (K), U1.2 (GPIO1)
Row 2: D27.1 (K), D28.1 (K), D29.1 (K), D30.1 (K), D31.1 (K), D32.1 (K), D33.1 (K), D34.1 (K), D35.1 (K), D36.1 (K), D37.1 (K), D38.1 (K), U1.9 (GPIO6)
Row 3: D39.1 (K), D40.1 (K), D41.1 (K), D42.1 (K), D43.1 (K), D44.1 (K), D45.1 (K), D46.1 (K), D47.1 (K), D48.1 (K), D49.1 (K), D50.1 (K), U1.10 (GPIO7)
Row 4: D51.1 (K), D52.1 (K), D53.1 (K), D54.1 (K), D55.1 (K), D56.1 (K), D57.1 (K), D58.1 (K), D59.1 (K), D60.1 (K), D61.1 (K), D62.1 (K), U1.11 (GPIO8)
SCL: U1.5 (GPIO3), U2.3 (SCL)
SDA: U1.4 (GPIO2), U2.4 (SDA)

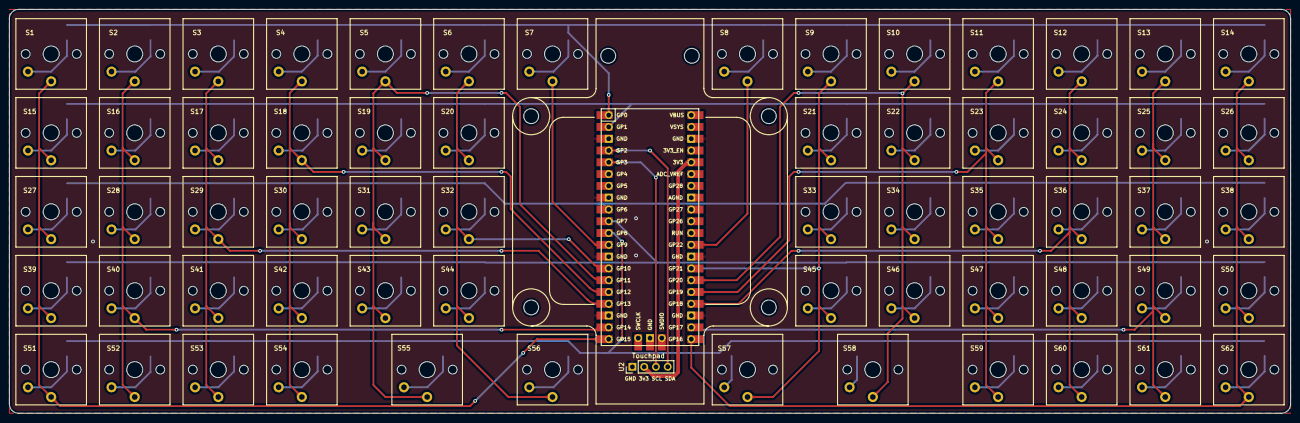
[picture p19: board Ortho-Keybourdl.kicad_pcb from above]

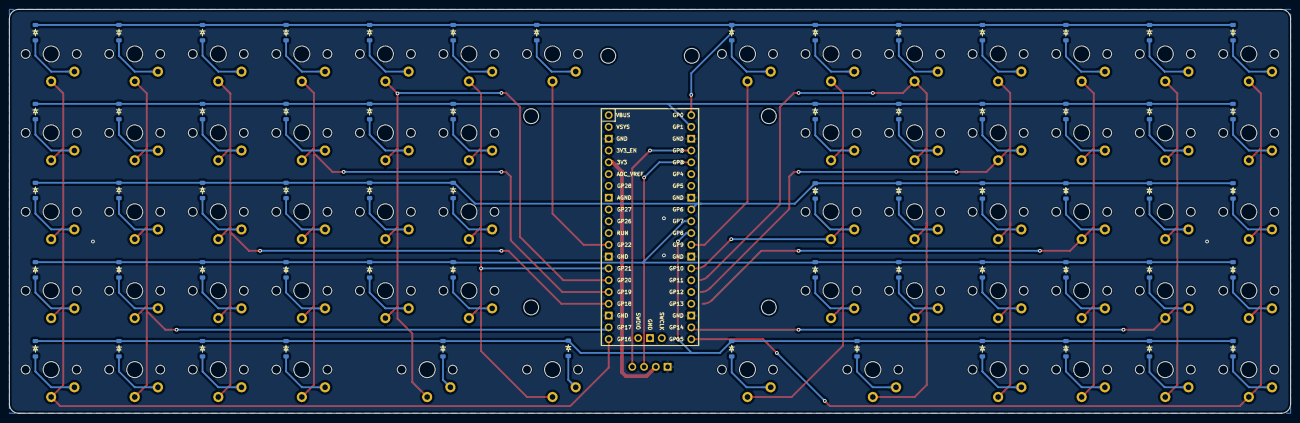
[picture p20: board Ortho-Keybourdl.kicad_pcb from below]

Board: 2 copper layers, 276.0 x 87.0 mm, 126 parts (62 on the bottom side), 85 nets.

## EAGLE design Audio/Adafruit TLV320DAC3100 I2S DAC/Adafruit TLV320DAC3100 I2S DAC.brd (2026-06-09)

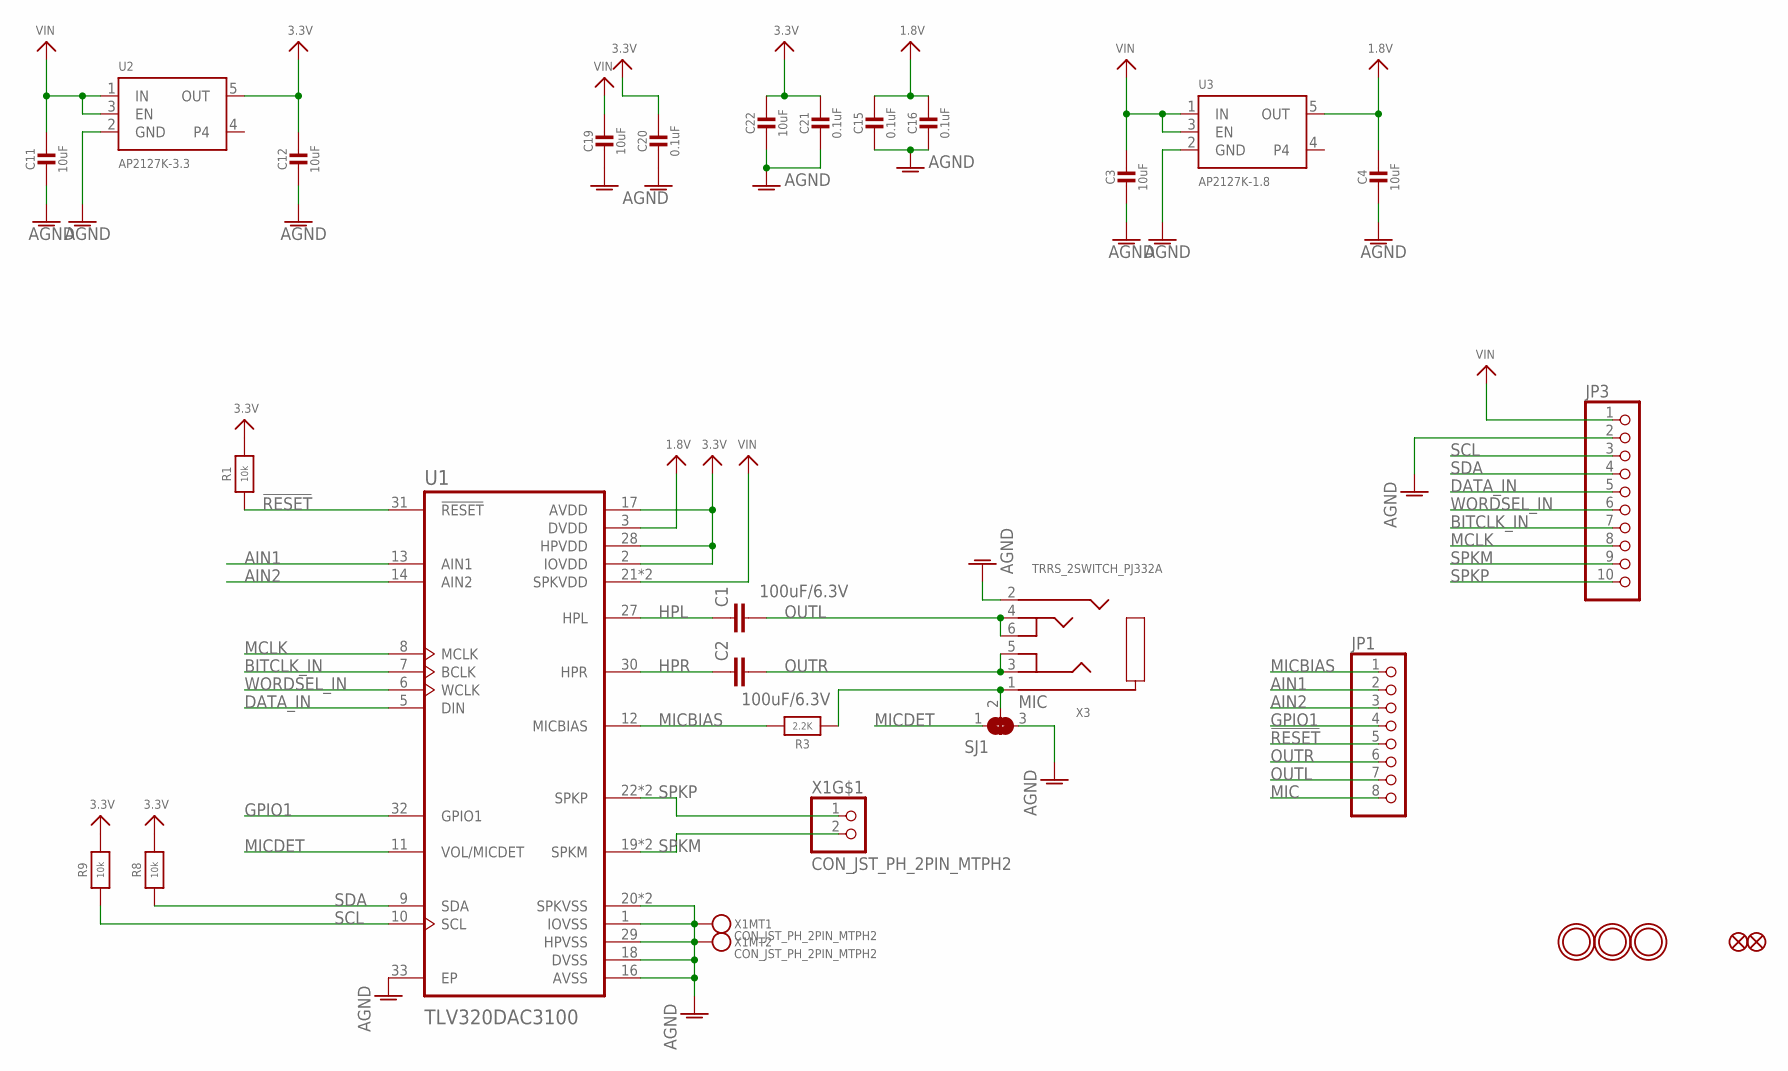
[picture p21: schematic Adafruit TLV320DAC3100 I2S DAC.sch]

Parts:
C1, C2: 100uF/6.3V; C1210
C3, C4, C11, C12, C19, C22: 10uF; 0805-NO
C15, C16, C20, C21: 0.1uF; 0603-NO
FID1, FID2: FIDUCIAL_0.5MM
JP1: HEADER-1X870MIL; 1X08_ROUND_70
JP3: HEADER-1X1070MIL; 1X10_ROUND70
R1, R8, R9: 10k; 0603-NO
R3: 2.2K; 0603-NO
SJ1: SOLDERJUMPER_2WAY; SOLDERJUMPER_2WAY_OPEN_NOPASTE
U1: TLV320DAC3100
U2: AP2127K-3.3; SOT23-5
U3: AP2127K-1.8; SOT23-5
U$12, U$13, U$14: MOUNTINGHOLE2.5; MOUNTINGHOLE_2.5_PLATED
X1: CON_JST_PH_2PIN_MTPH2; JSTPH2
X3: TRRS_2SWITCH_PJ332A; PJ-332A

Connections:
1.8V: C4.1, C15.1, C16.1, U1.3 (DVDD), U3.5 (OUT)
3.3V: C12.1, C20.1, C21.1, C22.1, R1.2, R8.2, R9.2, U1.2 (IOVDD), U1.17 (AVDD), U1.28 (HPVDD), U2.5 (OUT)
!RESET: JP1.5, R1.1, U1.31 (!RESET)
AGND: C3.2, C4.2, C11.2, C12.2, C15.2, C16.2, C19.2, C20.2, C21.2, C22.2, JP3.2, SJ1.3, U1.1 (IOVSS), U1.16 (AVSS), U1.18 (DVSS), U1.20 (SPKVSS), U1.25 (SPKVSS), U1.29 (HPVSS), U1.33 (EP), U2.2 (GND), U3.2 (GND), X1.NC1, X1.NC2, X3.2 (RING1)
AIN1: JP1.2, U1.13 (AIN1)
AIN2: JP1.3, U1.14 (AIN2)
BITCLK_IN: JP3.7, U1.7 (BCLK)
DATA_IN: JP3.5, U1.5 (DIN)
GPIO1: JP1.4, U1.32 (GPIO1)
HPL: C1.1, U1.27 (HPL)
HPR: C2.1, U1.30 (HPR)
MCLK: JP3.8, U1.8 (MCLK)
MIC: JP1.8, R3.1, SJ1.2, X3.1 (RING)
MICBIAS: JP1.1, R3.2, U1.12 (MICBIAS)
MICDET: SJ1.1, U1.11 (VOL/MICDET)
OUTL: C1.2, JP1.7, X3.4 (TIP), X3.6 (TIP_SW)
OUTR: C2.2, JP1.6, X3.3 (RING2), X3.5 (R2_SW)
SCL: JP3.3, R9.1, U1.10 (SCL)
SDA: JP3.4, R8.1, U1.9 (SDA)
SPKM: JP3.9, U1.19 (SPKM), U1.23 (SPKM), X1.2
SPKP: JP3.10, U1.22 (SPKP), U1.26 (SPKP), X1.1
VIN: C3.1, C11.1, C19.1, JP3.1, U1.21 (SPKVDD), U1.24 (SPKVDD), U2.1 (IN), U2.3 (EN), U3.1 (IN), U3.3 (EN)
WORDSEL_IN: JP3.6, U1.6 (WCLK)

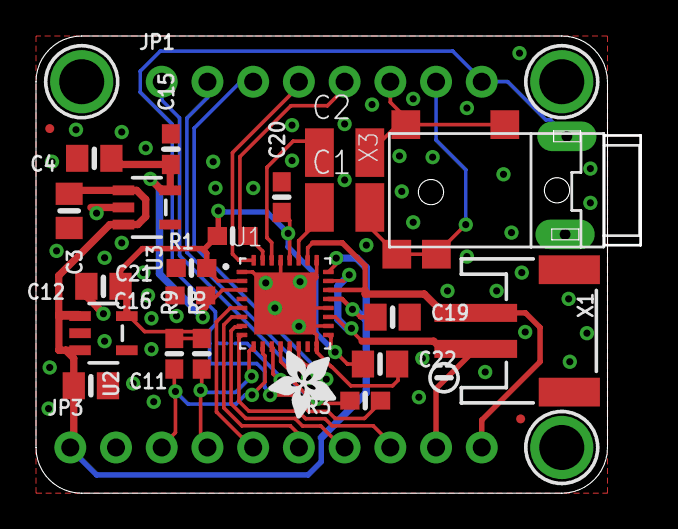
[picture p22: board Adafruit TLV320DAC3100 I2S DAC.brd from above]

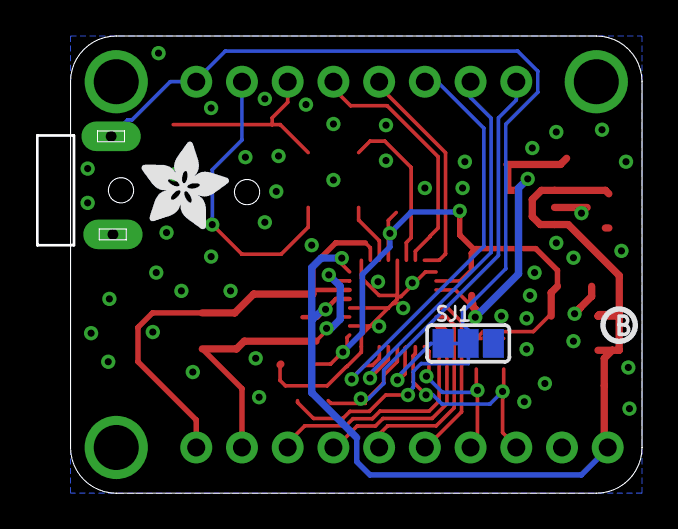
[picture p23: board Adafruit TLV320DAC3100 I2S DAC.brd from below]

Board: 2 copper layers, 33.6 x 25.4 mm, 60 parts (10 on the bottom side), 23 nets.

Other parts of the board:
E$1: SYMBOL_MINUS
PLABEL0: PLABEL0
PLABEL1: PLABEL1
PLABEL2: PLABEL2
PLABEL3: PLABEL3
PLABEL4: PLABEL4
PLABEL5: PLABEL5
PLABEL6: PLABEL6
PLABEL7: PLABEL7
PLABEL8: PLABEL8
PLABEL9: PLABEL9
PLABEL10: PLABEL10
PLABEL11: PLABEL11
PLABEL12: PLABEL12
PLABEL13: PLABEL13
PLABEL14: PLABEL14
PLABEL15: PLABEL15
PLABEL16: PLABEL16
PLABEL17: PLABEL17
PLABEL18: PLABEL18
PLABEL19: PLABEL19
PLABEL20: PLABEL20
PLABEL21: PLABEL21
PLABEL22: PLABEL22
PLABEL23: PLABEL23
PLABEL24: PLABEL24
PLABEL25: PLABEL25
PLABEL26: PLABEL26
U$5: PCBFEAT-REV-040
U$6: ADAFRUIT_5MM
U$29: ADAFRUIT_3.5MM

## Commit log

2026-06-25 Enhance README with hardware details and specifications
    Updated the README.md to provide detailed information about the keyboard, trackpad, laptop ports, power system, and battery life.
2026-09-04 Add links and Fix grammer
    Corrected typos and formatting issues throughout the README, including the spelling of 'LattePanda' and improved clarity in battery life descriptions.

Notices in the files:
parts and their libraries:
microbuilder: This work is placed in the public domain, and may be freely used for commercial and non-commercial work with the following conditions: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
